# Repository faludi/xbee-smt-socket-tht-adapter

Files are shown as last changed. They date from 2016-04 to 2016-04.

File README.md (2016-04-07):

# xbee-smt-socket-tht-adapter
XBee SMT Socket -> THT Adapter

This is a small adapter that reversibly installs a surface-mount XBee in place of a through-hole XBee. This means that modules like Digi's XBee 868LP that only come in a SMT version can be mounted on an XBee standard THT footprint without needing to permanently solder anything. The SMT XBee had to be rotated 90º so that its footprint does not conflict with the THT footprint underneath. All 20 pin connections have been tested and function as expected.

This adapter uses Digi's custom spring socket (part <a href="http://www.digikey.com/product-search/en?keywords=76002056">76002056</a>) as well as two sets of 10 pin, 2mm SMD connection headers. These <a href="http://www.digikey.com/product-search/en?keywords=SAM1172-11-nd">11-pin break-away headers</a> work well, just be sure to break off the extra left-facing pin.

Printed circuit boards can be ordered from <a href="https://oshpark.com/shared_projects/7I4gdVdC">OSH Park</a>.

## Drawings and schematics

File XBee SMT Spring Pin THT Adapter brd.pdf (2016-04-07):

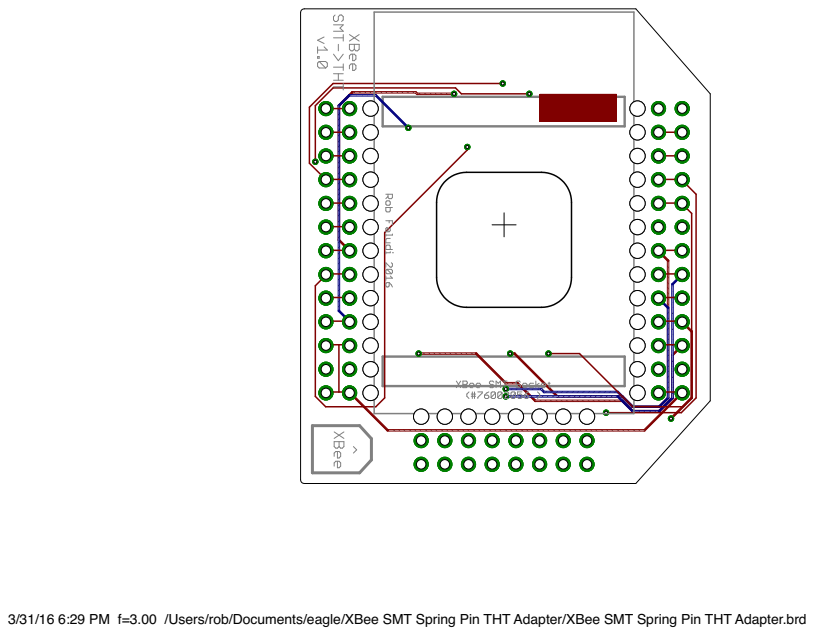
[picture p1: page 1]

3/31/16 6:29 PM f=3.00 /Users/rob/Documents/eagle/XBee SMT Spring Pin THT Adapter/XBee SMT Spring Pin THT Adapter.brd

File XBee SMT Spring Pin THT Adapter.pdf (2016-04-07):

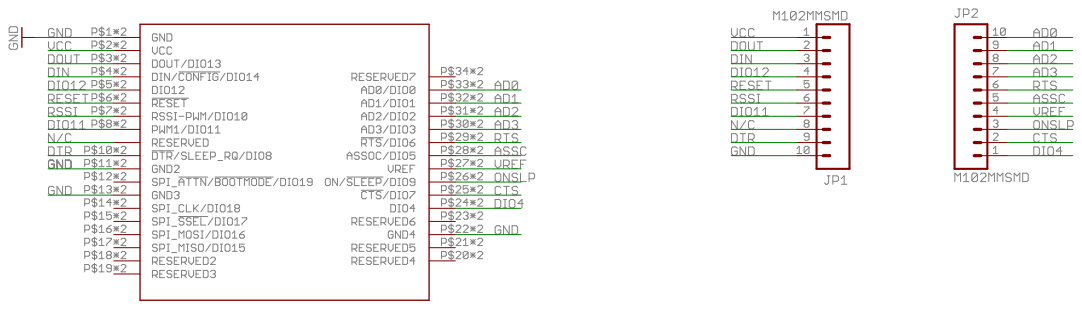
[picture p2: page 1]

3/31/16 6:28 PM f=0.99 /Users/rob/Documents/eagle/XBee SMT Spring Pin THT Adapter/XBee SMT Spring Pin THT Adapter.sch (Sheet: 1/1)

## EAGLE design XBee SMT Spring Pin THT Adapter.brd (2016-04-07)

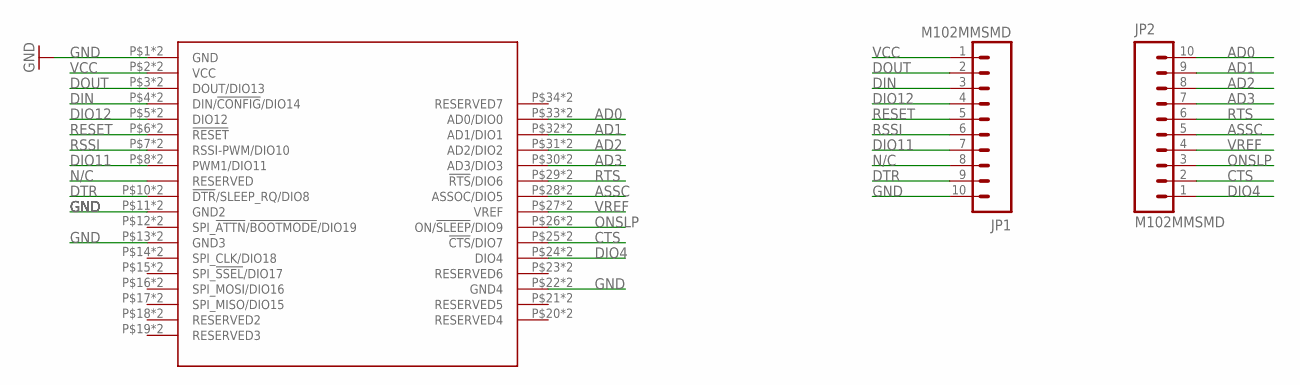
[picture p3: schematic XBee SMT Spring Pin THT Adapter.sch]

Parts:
JP1, JP2: M102MMSMD; 1X10-2MM-SMD
U$2: XBEE-SMT; XBEE_SMT_SPRING_SOCKET_SMALL_HOLE_76002056

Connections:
AD0: JP2.10, U$2.P$33 (AD0/DIO0), U$2.P$330 (AD0/DIO0)
AD1: JP2.9, U$2.P$32 (AD1/DIO1), U$2.P$320 (AD1/DIO1)
AD2: JP2.8, U$2.P$31 (AD2/DIO2), U$2.P$310 (AD2/DIO2)
AD3: JP2.7, U$2.P$30 (AD3/DIO3), U$2.P$300 (AD3/DIO3)
ASSC: JP2.5, U$2.P$28 (ASSOC/DIO5), U$2.P$280 (ASSOC/DIO5)
CTS: JP2.2, U$2.P$25 (!CTS!/DIO7), U$2.P$250 (!CTS!/DIO7)
DIN: JP1.3, U$2.P$4 (DIN/!CONFIG!/DIO14), U$2.P$040 (DIN/!CONFIG!/DIO14)
DIO4: JP2.1, U$2.P$24 (DIO4), U$2.P$240 (DIO4)
DIO11: JP1.7, U$2.P$8 (PWM1/DIO11), U$2.P$080 (PWM1/DIO11)
DIO12: JP1.4, U$2.P$5 (DIO12), U$2.P$050 (DIO12)
DOUT: JP1.2, U$2.P$3 (DOUT/DIO13), U$2.P$030 (DOUT/DIO13)
DTR: JP1.9, U$2.P$10 (!DTR!/SLEEP_RQ/DIO8), U$2.P$100 (!DTR!/SLEEP_RQ/DIO8)
GND: JP1.10, U$2.P$1 (GND), U$2.P$010 (GND), U$2.P$11 (GND2), U$2.P$13 (GND3), U$2.P$22 (GND4), U$2.P$110 (GND2), U$2.P$130 (GND3), U$2.P$220 (GND4)
N/C: JP1.8, U$2.P$9 (RESERVED), U$2.P$090 (RESERVED)
ONSLP: JP2.3, U$2.P$26 (ON/!SLEEP!/DIO9), U$2.P$260 (ON/!SLEEP!/DIO9)
RESET: JP1.5, U$2.P$6 (!RESET), U$2.P$060 (!RESET)
RSSI: JP1.6, U$2.P$7 (RSSI-PWM/DIO10), U$2.P$070 (RSSI-PWM/DIO10)
RTS: JP2.6, U$2.P$29 (!RTS!/DIO6), U$2.P$290 (!RTS!/DIO6)
VCC: JP1.1, U$2.P$2 (VCC), U$2.P$020 (VCC)
VREF: JP2.4, U$2.P$27 (VREF), U$2.P$270 (VREF)

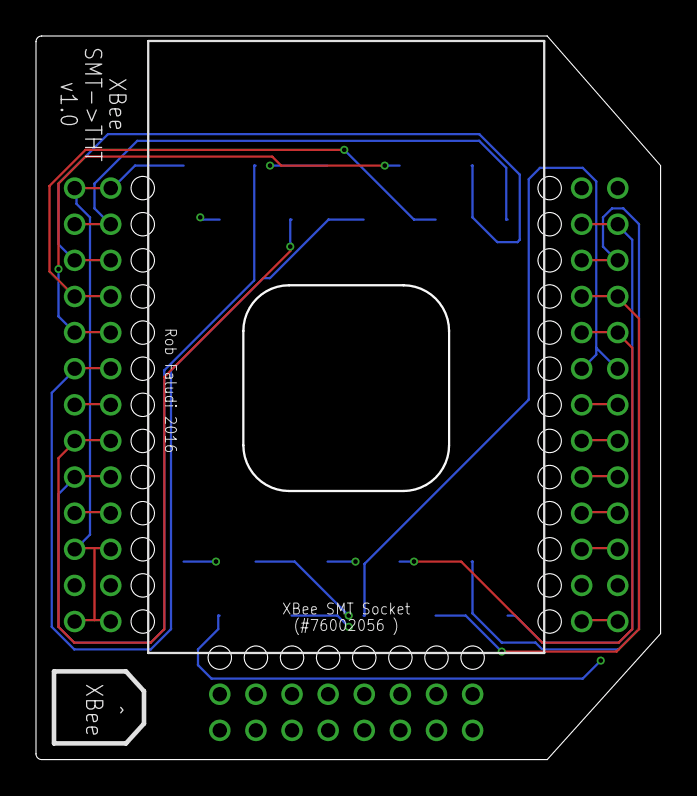
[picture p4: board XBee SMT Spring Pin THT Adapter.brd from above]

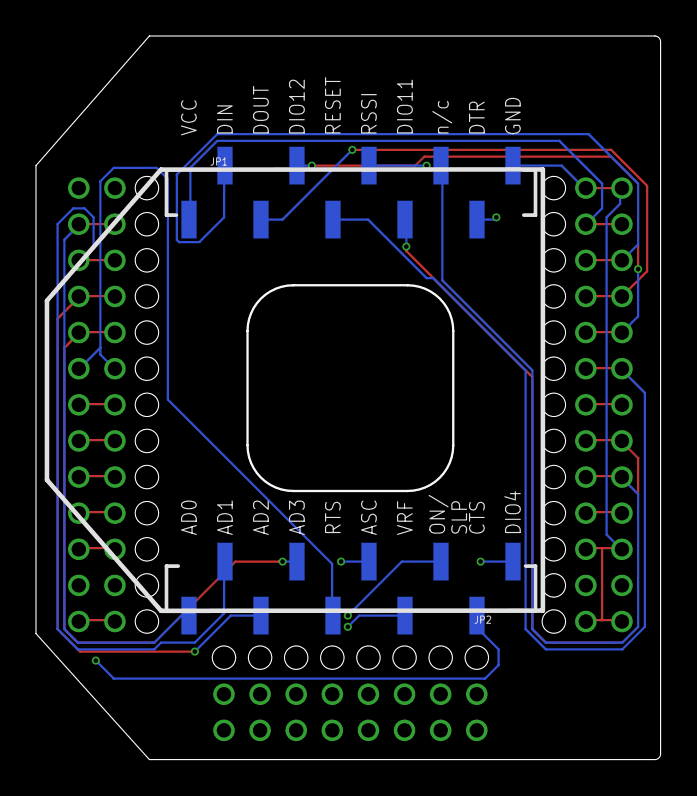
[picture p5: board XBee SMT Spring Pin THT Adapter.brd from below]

Board: 4 copper layers, 34.7 x 40.2 mm, 3 parts (2 on the bottom side), 20 nets.

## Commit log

2016-04-07 Schematic in PDF format
2016-04-07 Board layout in PDF format
2016-04-07 Eagle CAD design files
    [XBee SMT Spring Pin THT Adapter.brd, XBee SMT Spring Pin THT Adapter.sch]

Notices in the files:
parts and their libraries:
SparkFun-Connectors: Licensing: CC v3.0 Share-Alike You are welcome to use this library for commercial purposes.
